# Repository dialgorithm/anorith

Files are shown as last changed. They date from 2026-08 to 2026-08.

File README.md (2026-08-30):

<h1 align="center">
  anorith
  <br>
</h1>

<h4 align="center">
  a minimal rp2040 dev board with usb-c and onboard qspi flash.
</h4>

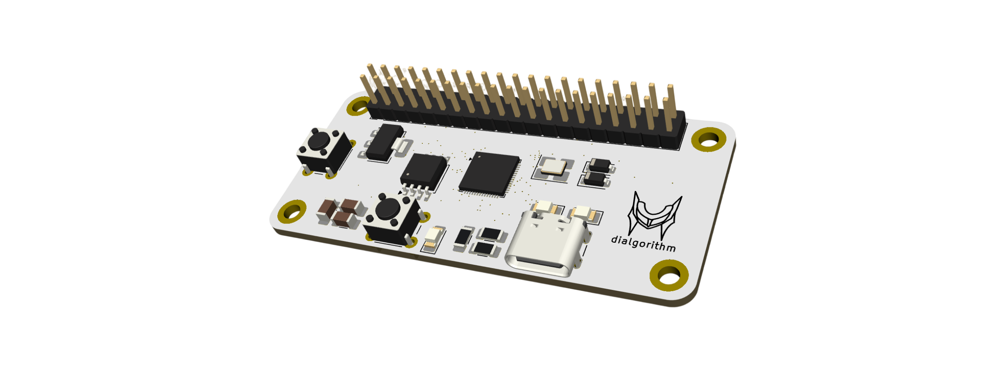
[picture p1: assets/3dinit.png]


## it features

- **RP2040** dual-core microcontroller as the main processor
- **W25Q16JVSS** 16 mbit qspi flash for program storage
- **reset and boot** buttons for flashing and resetting
- **status LEDs** for power and I/O indication

## design

**anorith** is a small, self-contained RP2040 board built around a compact 4-layer stackup.

the board is centered on the **rp2040**, with a **w25q16jvss** QSPI flash chip providing onboard storage for firmware, and an **ams1117-3.3** regulating the 3.3 V rail from USB. a **12 MHz crystal** clocks the RP2040, and a pair of schottky diodes handle power-path switching between usb and the header supply. the **usb-c connector**, **reset button**, and **boot button** sit along the board edge for easy access during programming.

## schematics + pcb design

| schematic | pcb |
| --- | --- |
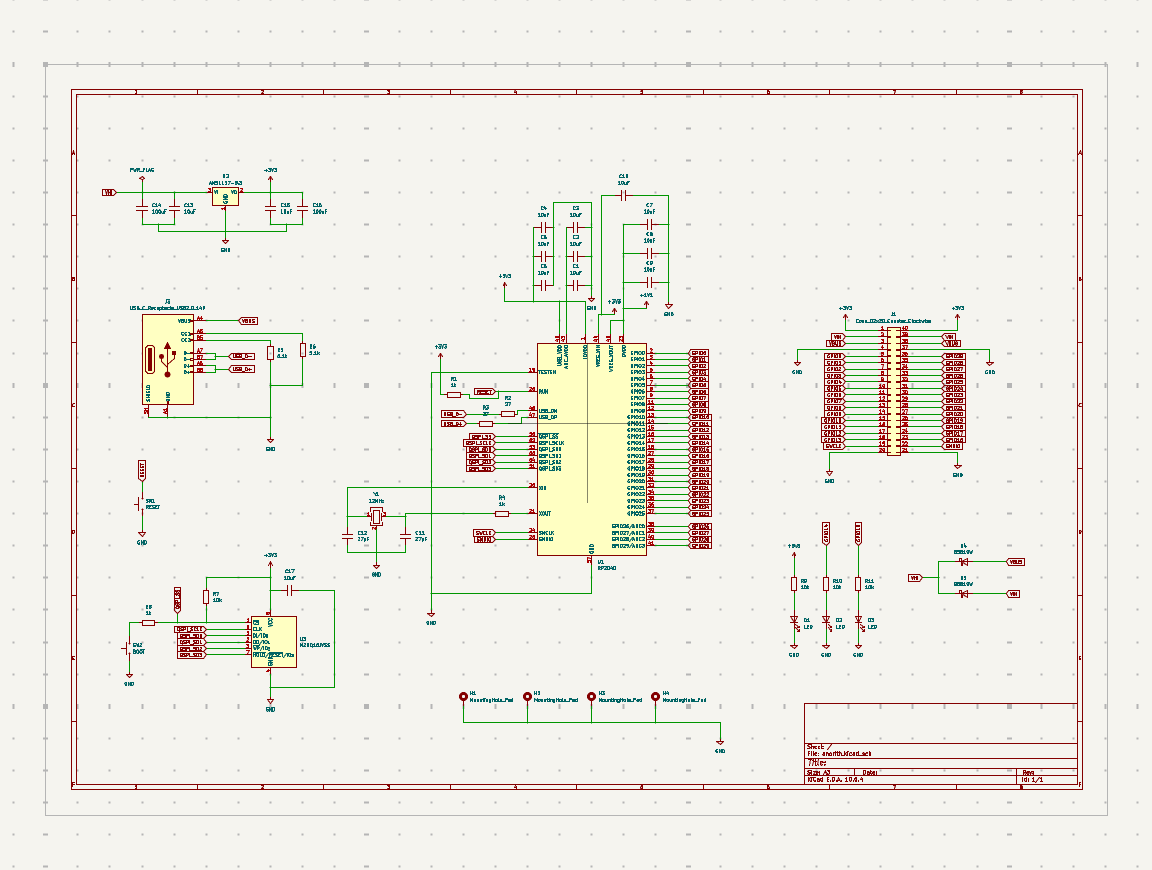
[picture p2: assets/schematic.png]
schematic
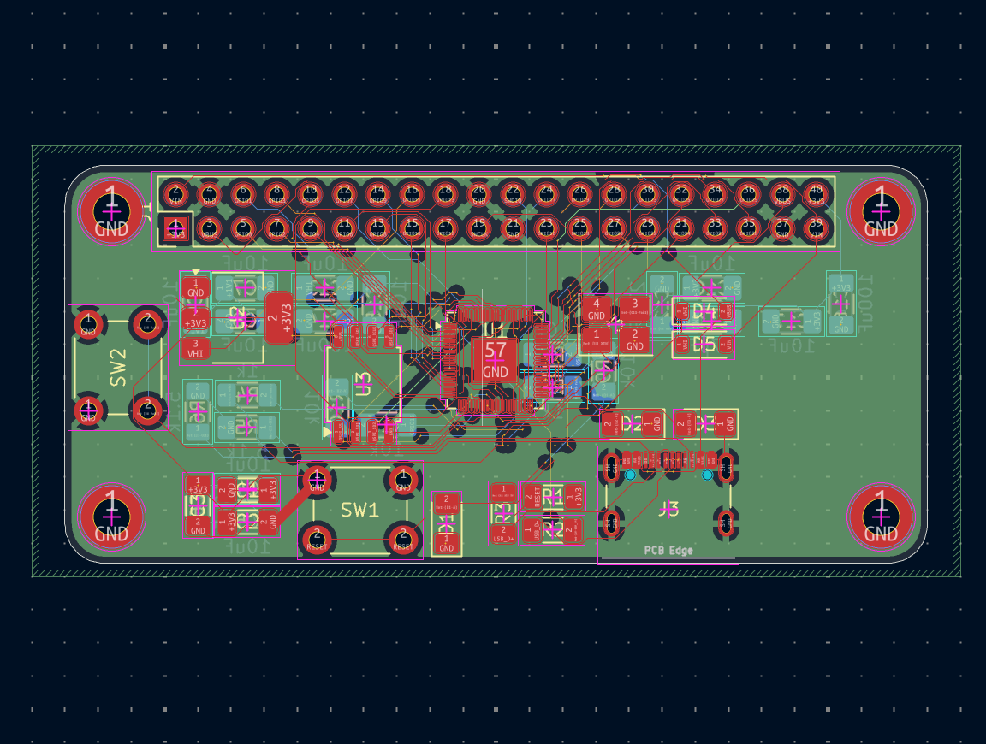
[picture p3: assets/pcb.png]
|  |  |

| first layer | second layer |
| --- | --- |
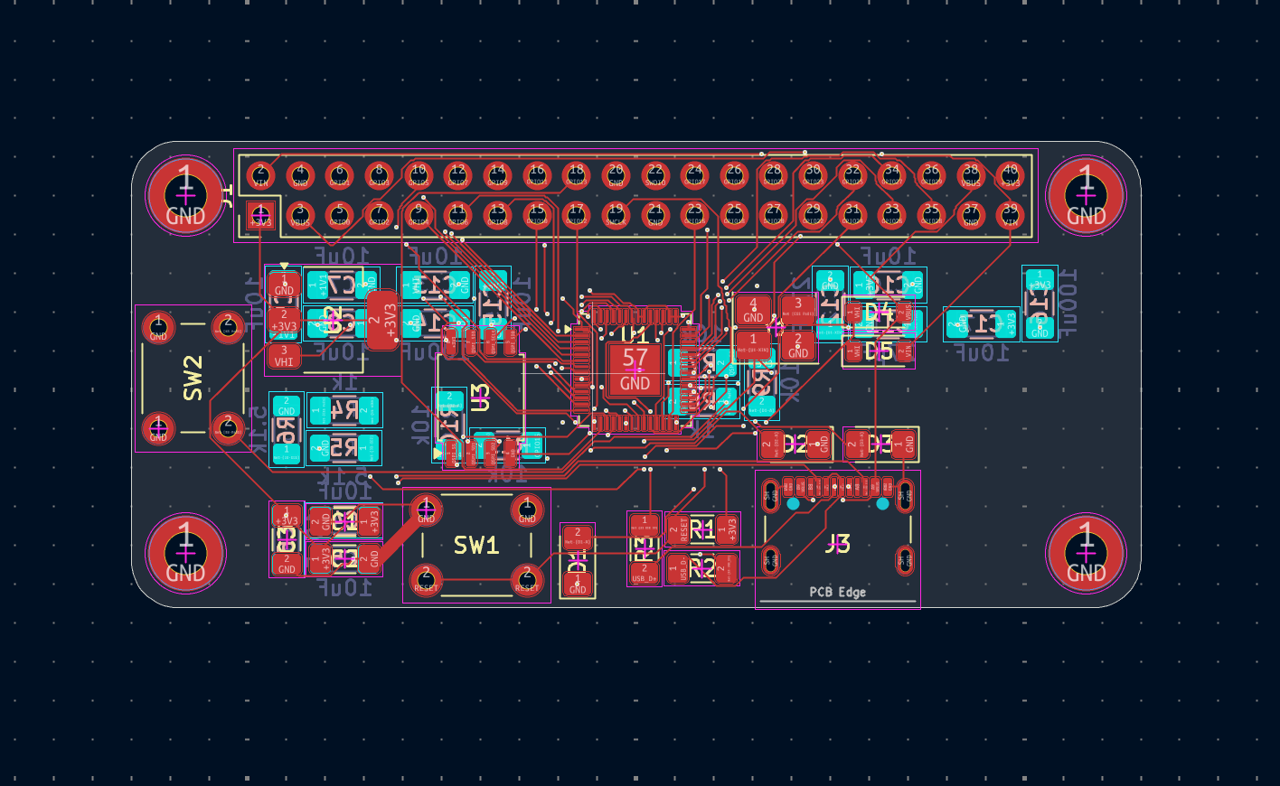
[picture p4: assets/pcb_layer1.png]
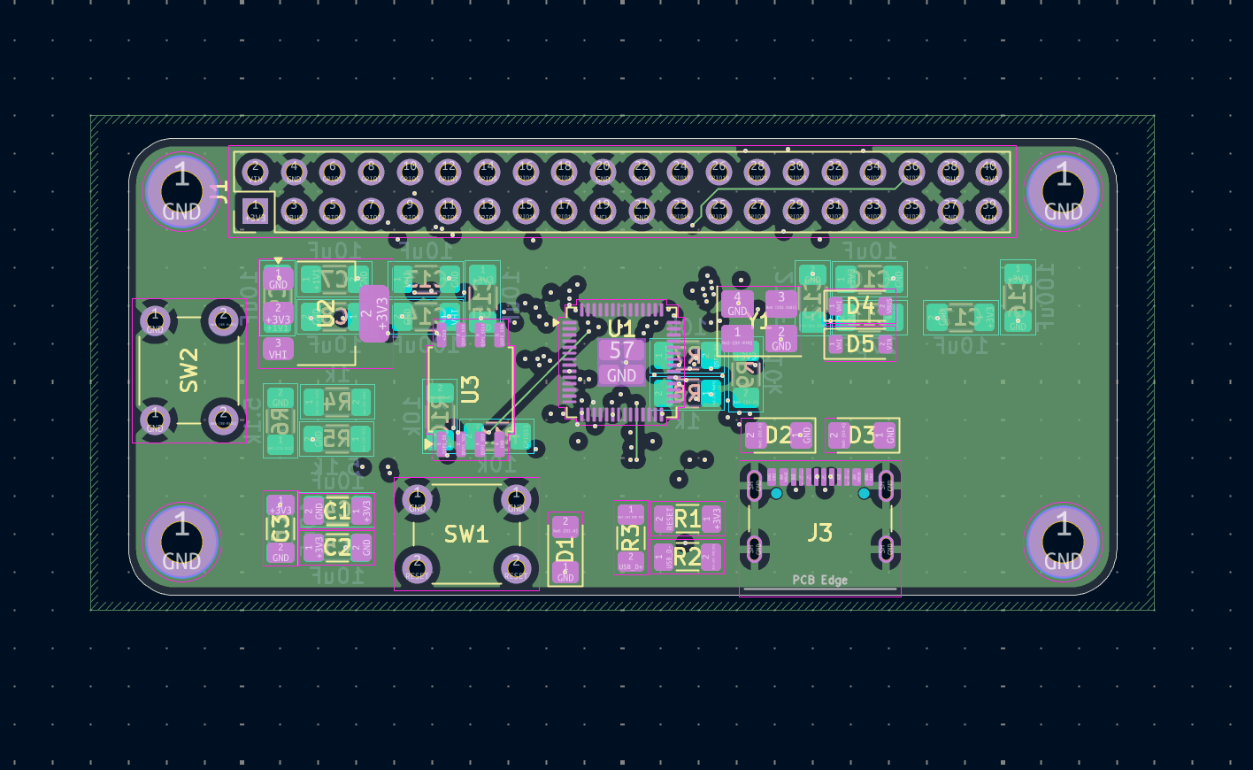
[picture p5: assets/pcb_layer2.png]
|  |  |

| third layer | fourth layer |
| --- | --- |
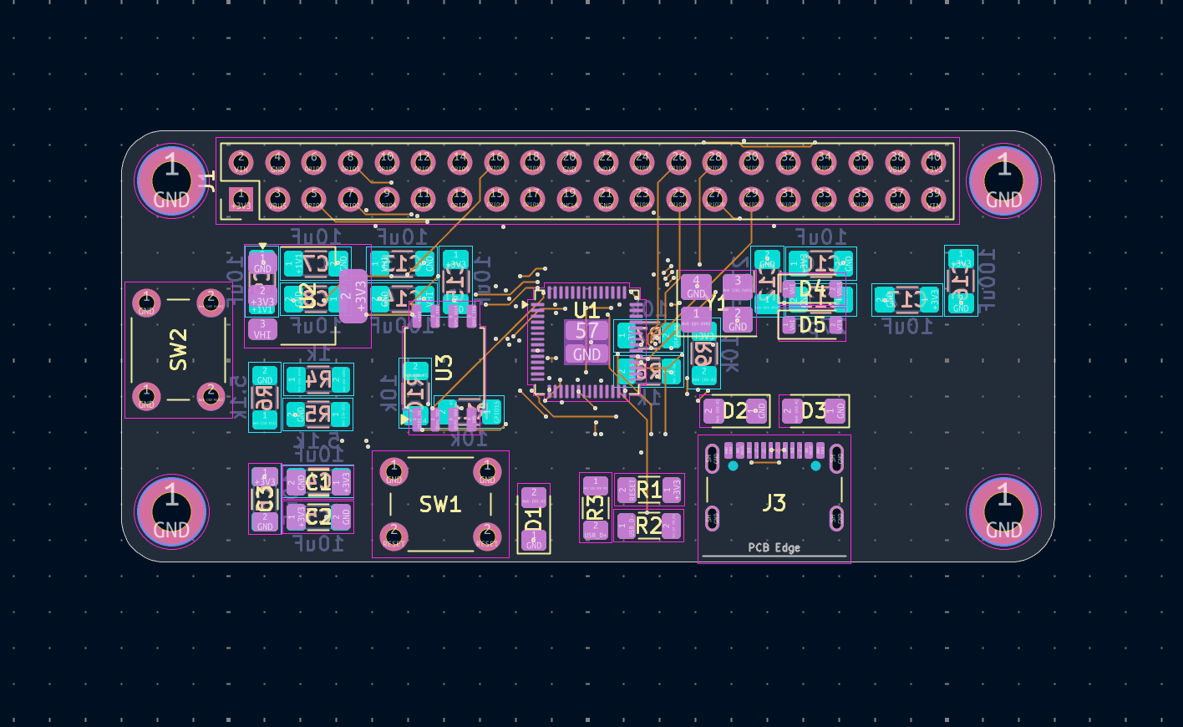
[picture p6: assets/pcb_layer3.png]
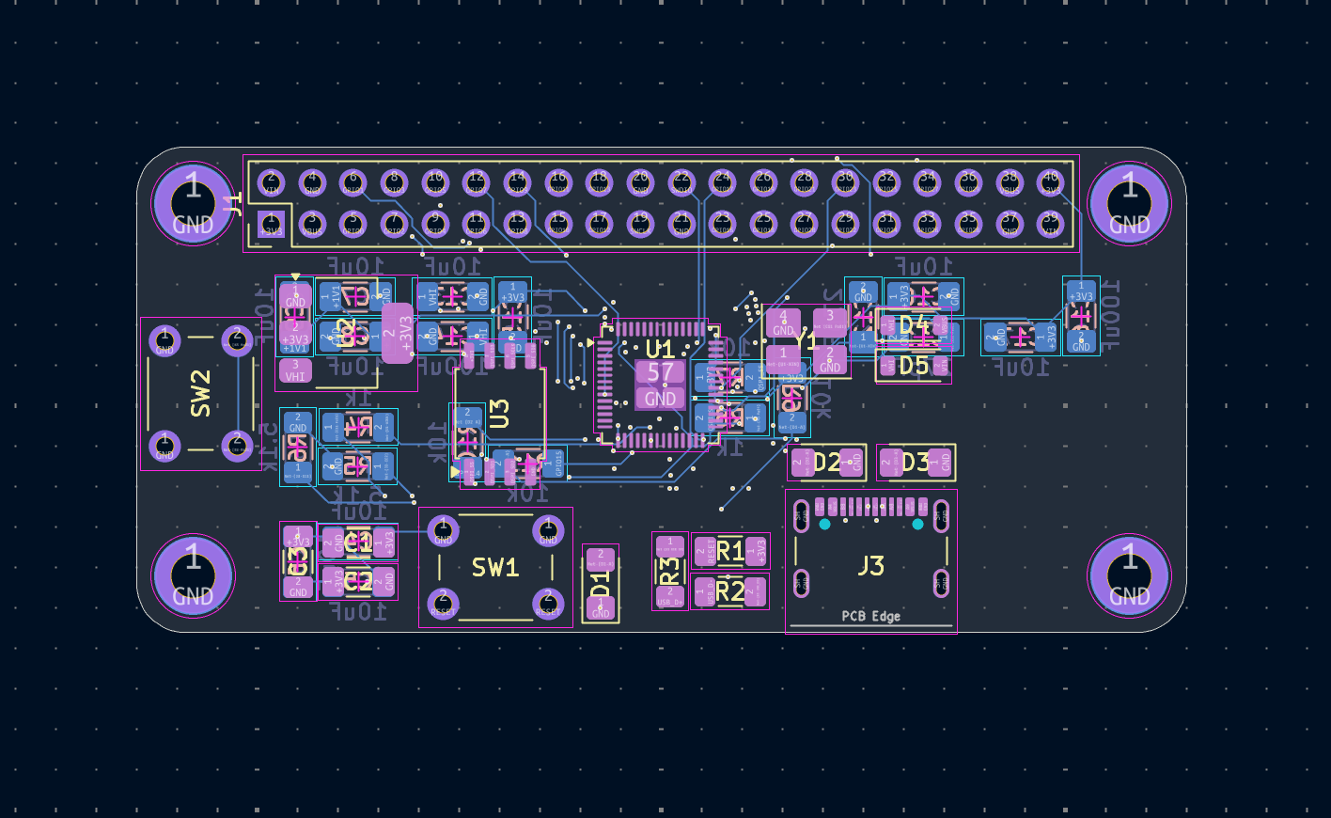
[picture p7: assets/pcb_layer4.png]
|  |  |

## BOM

the complete bill of materials is available in [`bom.csv`](bom.csv).

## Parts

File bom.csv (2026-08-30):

component | qty | cost | why | source
4 layer pcb | 5 | $29 | pcb fabrication | https://robu.in/product/online-pcb-manufacturing-service/
10uF 1206 Resistor | 26 | $5 | 13 per pcb | https://robu.in/product/grm319r61e106ka12d-murata-electronics-25v-10uf-x5r-%c2%b110-1206-multilayer-ceramic-capacitors-mlcc-smd-smt-rohs/
27pF 1206 Resistor | 4 | $1 | 2 per pcb | https://robu.in/product/tcc1206cog270j102et-cctc-smt-ceramic-capacitors-1206-cog-270j27pf%c2%b15-0-rated-voltage1000v-thickness1-00mm-tape/
100uF 1206 Resistor | 4 | $2.7 | 2 per pcb | https://robu.in/product/grm31cr61a107mea8l-murata-electronics-10v-100uf-x5r-%c2%b120-1206-multilayer-ceramic-capacitors-mlcc-smd-smt-rohs/
1206 package LED | 6 | $1 | 3 per pcb | https://robu.in/product/xl-3216ubc-fb-xinglight-reverse-mount-blue-120-1206-led-indication-discrete-rohs/
B5819W Schottky Diode | 4 | $1 | 2 per pcb | https://robu.in/product/b5819w-mdd-40v-independent-900mv3a-1a-sod-123-schottky-diodes-rohs/
2.54MM 2x20 Pin Female Double Row Header | 2 | $3.2 | 1 per pcb | https://robu.in/product/2-54mm-2x20-pin-female-double-row-straight-long-header-strip/
GCT USB C receptacle | 2 | $6.3 | connection | https://www.lioncircuits.com/parts/USB4105GFA120
1k 1206 Resistor | 6 | $1.5 | 3 per pcb | https://robu.in/product/1206w4f1001t5e-uniohm-royal-ohm-250mw-thick-film-resistors-200v-%c2%b11-1k%cf%89-1206-chip-resistor-surface-mount-rohs/
10k 1206 Resistor | 8 | $1.3 | 4 per pcb | https://robu.in/product/rc1206fr-0710kl-yageo-res-thick-film-1206-10k-ohm-1-0-25w1-4w-%c2%b1100ppm-c-pad-smd-t-r/
27Ω 1206 Resistor | 4 | $1.5 | 2 per pcb | https://robu.in/product/rt1206fre0727rl-yageo-250mw-thin-film-resistor-200v-%c2%b150ppm-%e2%84%83-%c2%b11-27%cf%89-1206-chip-resistor-surface-mount-rohs/
5.1k 1206 Resistor | 4 | $1.7 | 2 per pcb | https://robu.in/product/1206w4f5101t5e-uniohm-royal-ohm-250mw-thick-film-resistors-200v-%c2%b1100ppm-%e2%84%83-%c2%b11-5-1k%cf%89-1206-chip-resistor-surface-m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
Raspberry Pi RP2040 IC | 2 | $3.2 | brain | https://robu.in/product/raspberry-pi-rp2040/
6mm Tactile switch | 4 | $1 | 2 per pcb | https://robu.in/product/tsd003a06026b-bzcn-6mm-6mm-50ma-round-button-standing-paste-6mm-12v-smd-tactile-switches-rohs/
AMS1117-3.3 LDO Regulator | 2 | $1 | low drop regulation | https://robu.in/product/ams1117-3-3-kexin-1a-fixed-3-3v-positive-electrode-18v-sot-223-4-voltage-regulators-linear-low-drop-out-ldo-regulators-rohs/
W25Q32JVSSIQ Winbond Memory IC | 2 | $3.2 | memory | https://robu.in/product/w25q32jvssiq-winbond/
12MHz SMD Crystal Oscillator | 2 | $4.2 | oscillate | https://www.amazon.in/12MHz-Crystal-Oscillator-6pcs-SMD3225-4P/dp/B0G7JN6FLK
Total | - | $75 | - | -

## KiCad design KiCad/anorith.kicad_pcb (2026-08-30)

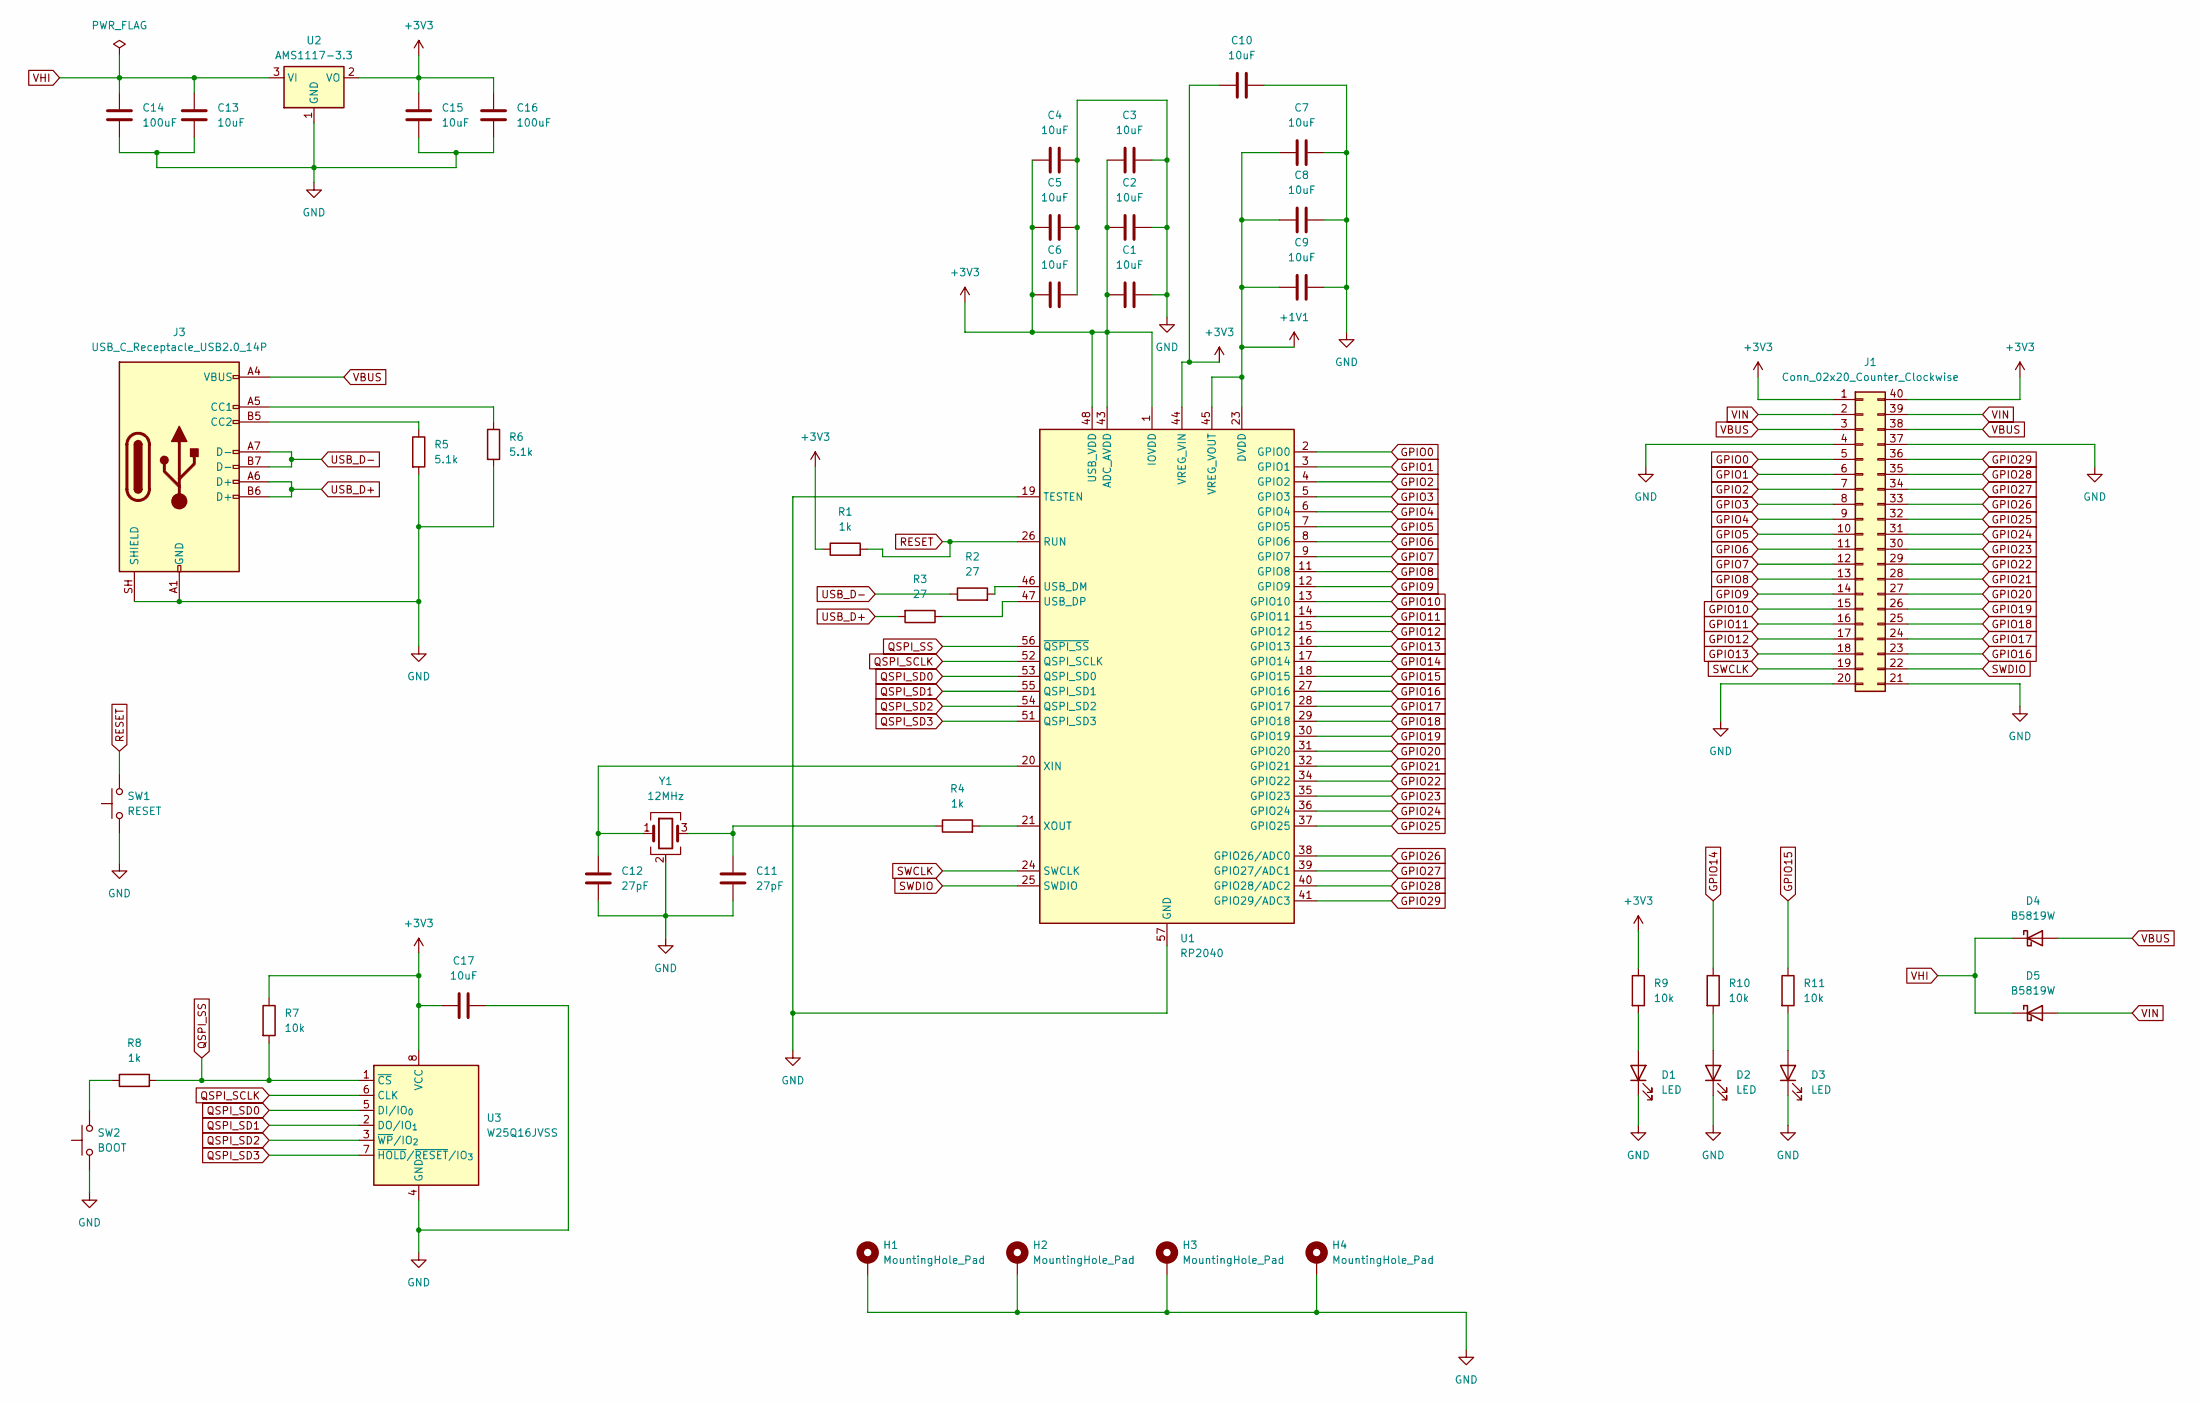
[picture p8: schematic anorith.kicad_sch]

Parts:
C1, C2, C3, C4, C5, C6, C7, C8, C9, C10, C13, C15, C17: 10uF; C_1206_3216Metric_Pad1.33x1.80mm_HandSolder
C11, C12: 27pF; C_1206_3216Metric_Pad1.33x1.80mm_HandSolder
C14, C16: 100uF; C_1206_3216Metric_Pad1.33x1.80mm_HandSolder
D1, D2, D3: LED; LED_1206_3216Metric_Pad1.42x1.75mm_HandSolder
D4, D5: B5819W; D_SOD-123
H1, H2, H3, H4: MountingHole_Pad; MountingHole_2.7mm_M2.5_DIN965_Pad
J1: Conn_02x20_Counter_Clockwise; PinHeader_2x20_P2.54mm_Vertical
J3: USB_C_Receptacle_USB2.0_14P; USB_C_Receptacle_GCT_USB4105-xx-A_16P_TopMnt_Horizontal
R1, R4, R8: 1k; R_1206_3216Metric_Pad1.30x1.75mm_HandSolder
R2, R3: 27; R_1206_3216Metric_Pad1.30x1.75mm_HandSolder
R5, R6: 5.1k; R_1206_3216Metric_Pad1.30x1.75mm_HandSolder
R7, R9, R10, R11: 10k; R_1206_3216Metric_Pad1.30x1.75mm_HandSolder
SW1: RESET; SW_PUSH_6mm
SW2: BOOT; SW_PUSH_6mm
U1: RP2040; QFN-56-1EP_7x7mm_P0.4mm_EP3.2x3.2mm
U2: AMS1117-3.3; SOT-223-3_TabPin2
U3: W25Q16JVSS; SOIC-8_5.3x5.3mm_P1.27mm
Y1: 12MHz; Crystal_SMD_3225-4Pin_3.2x2.5mm_HandSoldering

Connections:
+1V1: C7.1, C8.1, C9.1, U1.23 (DVDD), U1.45 (VREG_VOUT), U1.50 (DVDD)
+3V3: C1.1, C2.1, C3.1, C4.1, C5.1, C6.1, C10.1, C15.1, C16.1, C17.1, J1.1, J1.40, R1.1, R7.1, R9.1, U1.1 (IOVDD), U1.10 (IOVDD), U1.22 (IOVDD), U1.33 (IOVDD), U1.42 (IOVDD), U1.43 (ADC_AVDD), U1.44 (VREG_VIN), U1.48 (USB_VDD), U1.49 (IOVDD), U2.2 (VO), U3.8 (VCC)
GND: C1.2, C2.2, C3.2, C4.2, C5.2, C6.2, C7.2, C8.2, C9.2, C10.2, C11.2, C12.2, C13.2, C14.2, C15.2, C16.2, C17.2, D1.1 (K), D2.1 (K), D3.1 (K), H1.1 (1_1), H2.1 (1_1), H3.1 (1_1), H4.1 (1_1), J1.4, J1.20, J1.21, J1.37, J3.A1 (GND), J3.A12 (GND), J3.B1 (GND), J3.B12 (GND), J3.SH (SHIELD), R5.2, R6.2, SW1.1, SW2.1, U1.19 (TESTEN), U1.57 (GND), U2.1 (GND), U3.4 (GND), Y1.2 (G), Y1.4 (G)
GPIO0: J1.5, U1.2 (GPIO0)
GPIO1: J1.6, U1.3 (GPIO1)
GPIO2: J1.7, U1.4 (GPIO2)
GPIO3: J1.8, U1.5 (GPIO3)
GPIO4: J1.9, U1.6 (GPIO4)
GPIO5: J1.10, U1.7 (GPIO5)
GPIO6: J1.11, U1.8 (GPIO6)
GPIO7: J1.12, U1.9 (GPIO7)
GPIO8: J1.13, U1.11 (GPIO8)
GPIO9: J1.14, U1.12 (GPIO9)
GPIO10: J1.15, U1.13 (GPIO10)
GPIO11: J1.16, U1.14 (GPIO11)
GPIO12: J1.17, U1.15 (GPIO12)
GPIO13: J1.18, U1.16 (GPIO13)
GPIO14: R10.1, U1.17 (GPIO14)
GPIO15: R11.1, U1.18 (GPIO15)
GPIO16: J1.23, U1.27 (GPIO16)
GPIO17: J1.24, U1.28 (GPIO17)
GPIO18: J1.25, U1.29 (GPIO18)
GPIO19: J1.26, U1.30 (GPIO19)
GPIO20: J1.27, U1.31 (GPIO20)
GPIO21: J1.28, U1.32 (GPIO21)
GPIO22: J1.29, U1.34 (GPIO22)
GPIO23: J1.30, U1.35 (GPIO23)
GPIO24: J1.31, U1.36 (GPIO24)
GPIO25: J1.32, U1.37 (GPIO25)
GPIO26: J1.33, U1.38 (GPIO26/ADC0)
GPIO27: J1.34, U1.39 (GPIO27/ADC1)
GPIO28: J1.35, U1.40 (GPIO28/ADC2)
GPIO29: J1.36, U1.41 (GPIO29/ADC3)
unnamed: C11.1, R4.1, Y1.3
unnamed: D1.2 (A), R9.2
unnamed: D2.2 (A), R10.2
unnamed: D3.2 (A), R11.2
unnamed: J3.A5 (CC1), R6.1
unnamed: J3.B5 (CC2), R5.1
unnamed: R8.1, SW2.2
unnamed: R2.2, U1.46 (USB_DM)
unnamed: R3.1, U1.47 (USB_DP)
unnamed: C12.1, U1.20 (XIN), Y1.1
unnamed: R4.2, U1.21 (XOUT)
QSPI_SCLK: U1.52 (QSPI_SCLK), U3.6 (CLK)
QSPI_SD0: U1.53 (QSPI_SD0), U3.5 (DI/IO_{0})
QSPI_SD1: U1.55 (QSPI_SD1), U3.2 (DO/IO_{1})
QSPI_SD2: U1.54 (QSPI_SD2), U3.3 (~WP/IO_{2})
QSPI_SD3: U1.51 (QSPI_SD3), U3.7 (~HOLD/~RESET/IO_{3})
QSPI_SS: R7.2, R8.2, U1.56 (~QSPI_SS), U3.1 (~CS)
RESET: R1.2, SW1.2, U1.26 (RUN)
SWCLK: J1.19, U1.24 (SWCLK)
SWDIO: J1.22, U1.25 (SWDIO)
USB_D+: J3.A6 (D+), J3.B6 (D+), R3.2
USB_D-: J3.A7 (D-), J3.B7 (D-), R2.1
VBUS: D4.2 (A), J1.3, J1.38, J3.A4 (VBUS), J3.A9 (VBUS), J3.B4 (VBUS), J3.B9 (VBUS)
VHI: C13.1, C14.1, D4.1 (K), D5.1 (K), U2.3 (VI)
VIN: D5.2 (A), J1.2, J1.39

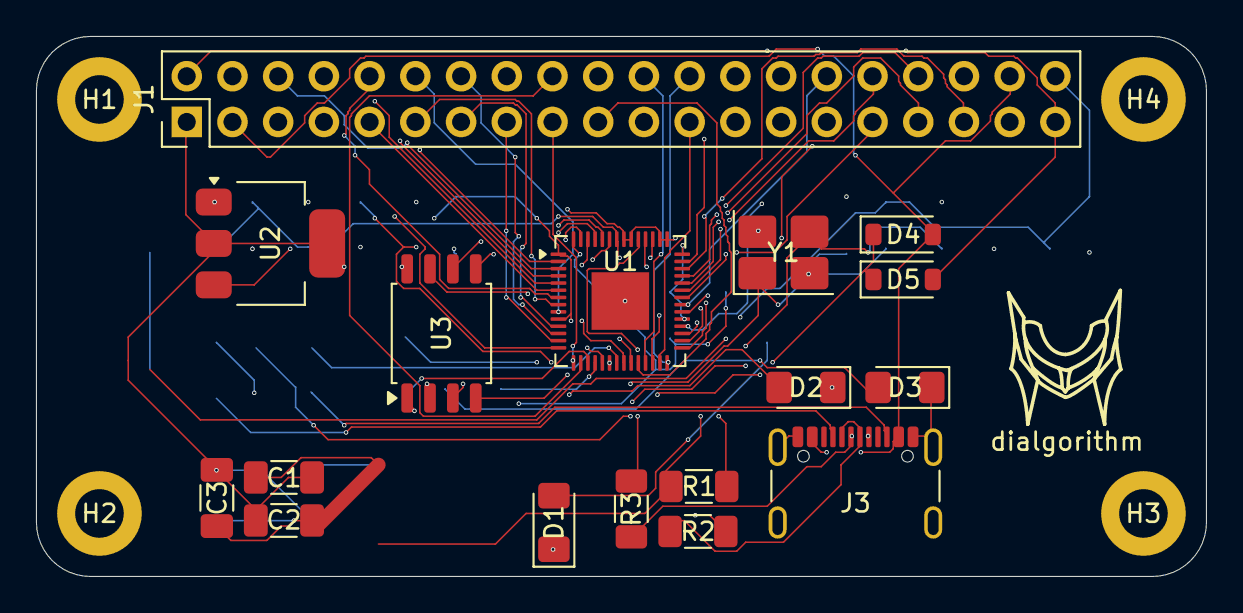
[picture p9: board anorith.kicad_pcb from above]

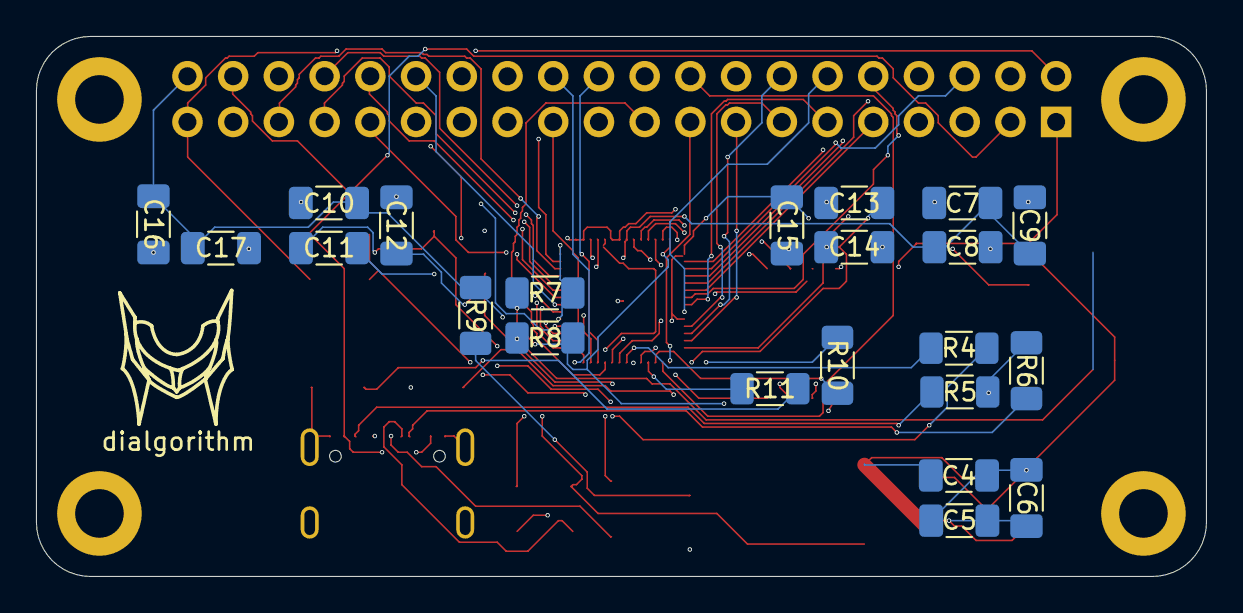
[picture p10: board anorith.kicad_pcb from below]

Board: 4 copper layers, 65.0 x 30.0 mm, 45 parts (23 on the bottom side), 57 nets.

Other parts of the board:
dialgorithm: dialgorithm
dialgorithm#2: dialgorithm
